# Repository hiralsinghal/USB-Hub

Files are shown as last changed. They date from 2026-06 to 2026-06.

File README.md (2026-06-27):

# USB-Hub

This is a USB hub. It has a USB-C port to connect to the device. It has two USB-A ports and two USB-C ports, which can be used for connecting more devices as it allows you to increase the number of ports available.

## Features

- USB-C port to form the connection between the hub and your device.
- 2 USB-A ports
- 2 USB-C ports

## Schematic

This is the schematic for the USB hub. It has an IC, which makes the hub work. 

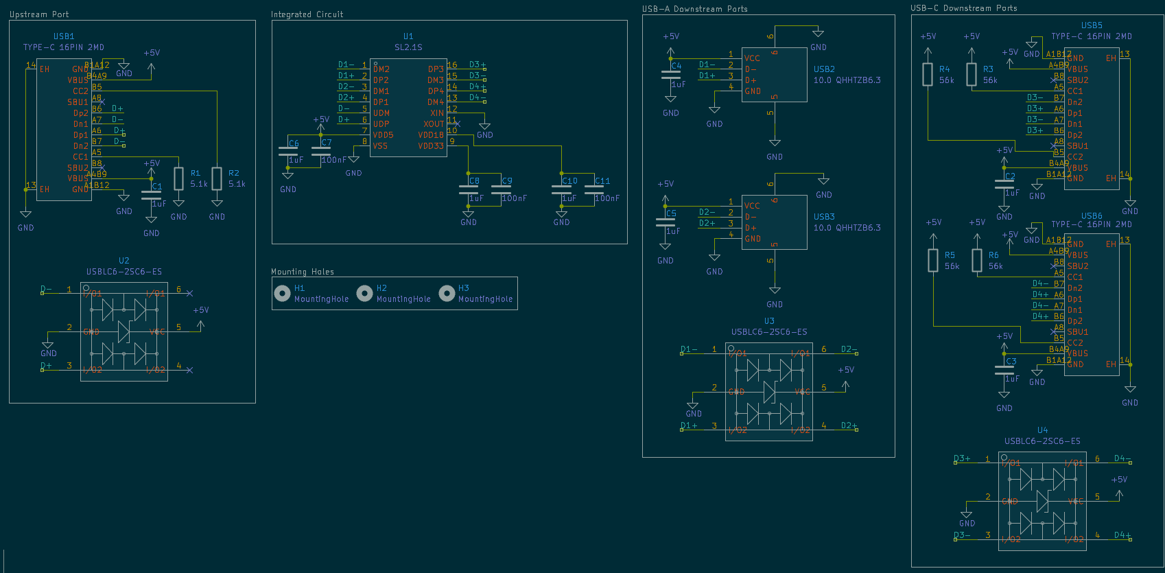
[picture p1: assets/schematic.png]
schematic


### Upstream Port

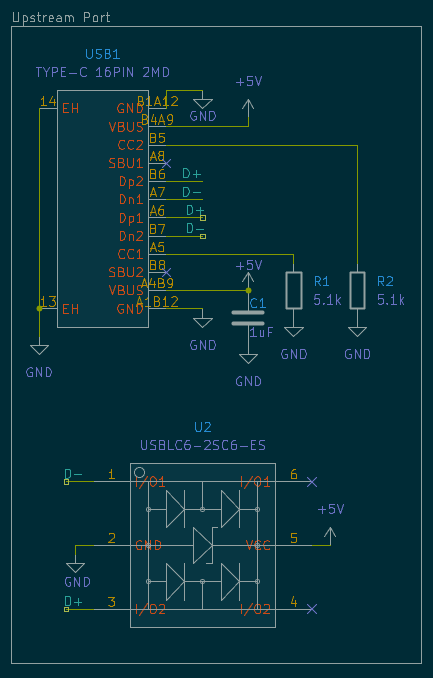
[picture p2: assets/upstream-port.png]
upstream port schematic


### Integrated Circuit

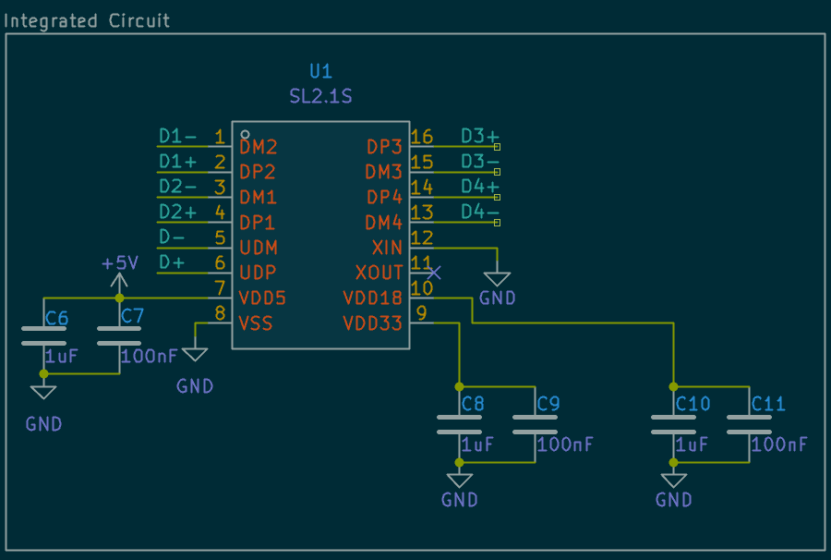
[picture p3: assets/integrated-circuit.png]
integrated circuit schematic


### Downstream Ports

#### USB-A

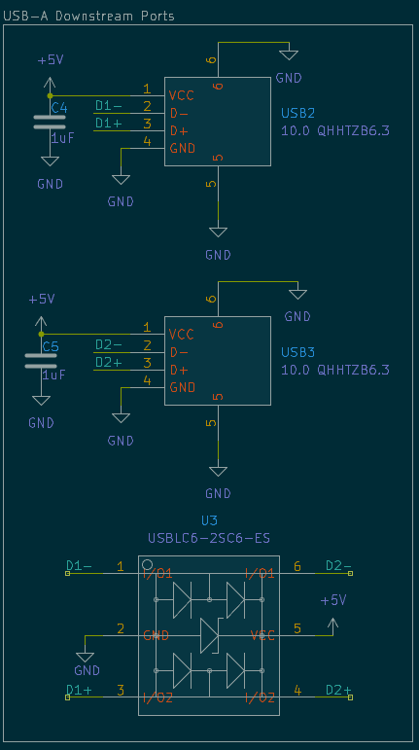
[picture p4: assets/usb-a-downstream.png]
downstream usb-a ports schematic


#### USB-C

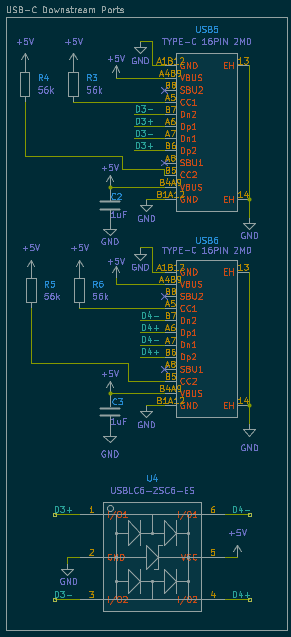
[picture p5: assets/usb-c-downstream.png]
downstream usb-c ports schematic


## PCB

Its just a rounded rectangle shaped PCB and has three mounting holes, so it can be screwed into the case.
I added some quotes as silkscreen art.

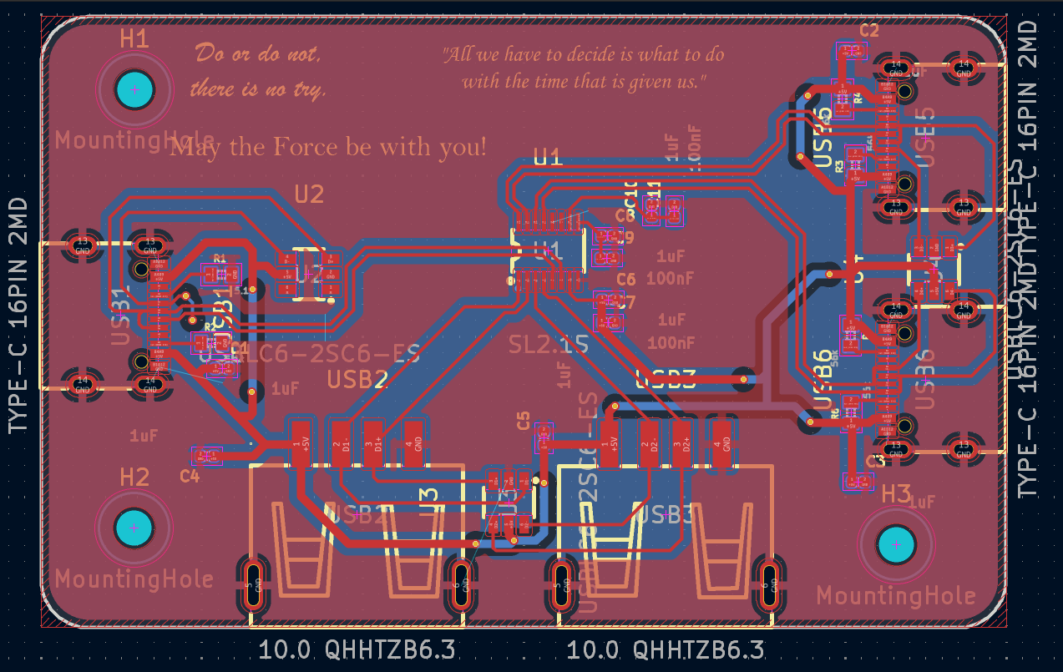
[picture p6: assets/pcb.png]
pcb


**No zones**

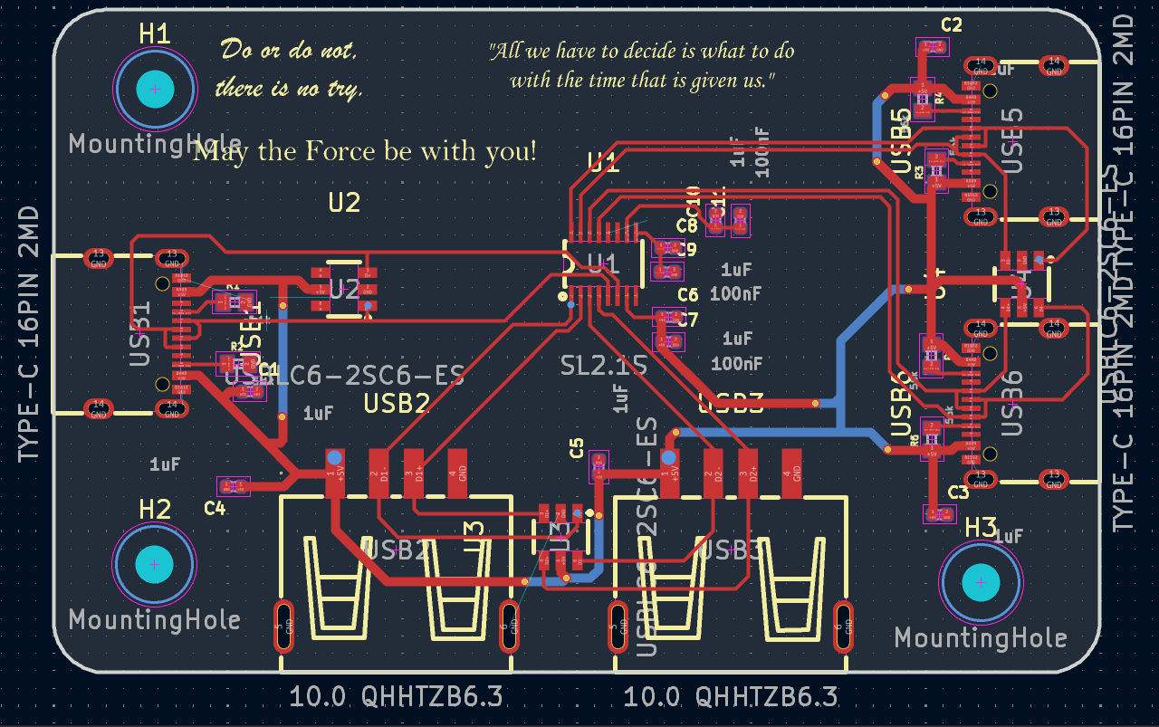
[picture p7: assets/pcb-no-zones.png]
pcb with no filled zones


## Case

I designed this in Fusion, using my PCB as a guide. It has holes for M3 screws so the bottom and top parts hold together. You can find the files in the CAD folder.

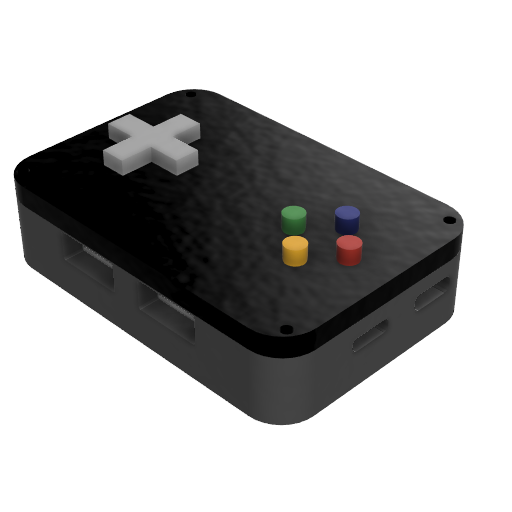
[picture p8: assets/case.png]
case


## BOM

For a more detailed BOM, take a look at [BOM](bom.csv). It has links to the items and notes.

| Item | Description | Quantity | Unit Price ($) | Total Price ($) |
| --- | --- | --- | --- | --- |
| JLCPCB PCB | PCB | 5 | 0.8 | 4 |
| CoreChips SL2.1s | USB 2.0 HUB Controller Integrated Circuit | 5 | 0.2534 | 1.27 |
| SHOU HAN 10.0 QHHTZB6.3 | CONN RCPT USB 2.0 Type-A 4POS SMD R/A | 10 | 0.0636 | 0.64 |
| SHOU HAN TYPE-C 16PIN 2MD(073) | CONN RCPT Type-C 16POS SMD R/A | 20 | 0.0707 | 1.41 |
| ElecSuper USBLC6-2SC6-ES | ESD DIODE 5VWM 15VC SOT-23-6L | 20 | 0.0278 | 0.56 |
| 10k Resistor SMD:R 0402 | Resistor | 6 | 0.0083 | 0.0498 |
| 0.1uf Capacitor SMD:C 0402 | Capacitor | 11 | 0.011 | 0.121 |
| <b>Total</b> | | | | 8.0508 |

## Assembly

- Solder the components to the PCB.
- Print the case.
- Screw the PCB and the bottom case together so its stable.
- Screw the bottom and top case together.
- You have your USB hub!

## Zine

This was designed in Figma. It wasn't easy to make. I had no ideas. I was stuck. Its not my best work.

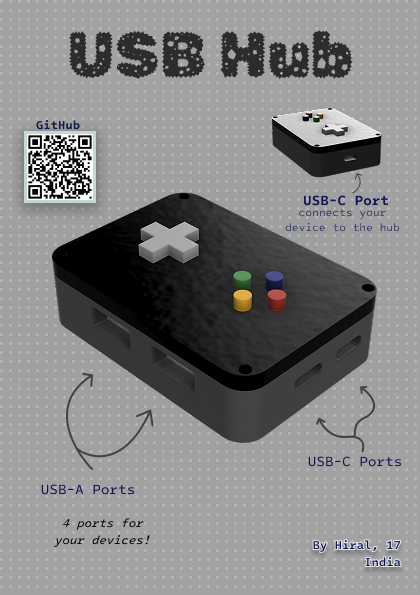
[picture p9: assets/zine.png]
zine


## Why did I make it?

I have been trying to get more into hardware, making guided projets before jumping in to make something my own.
I want to have knowledge on how to do this stuff, so I know how to make my own project.
My routing skills were improved. I made them neatly.

This project was submitted to [Fallout](fallout.hackclub.com).

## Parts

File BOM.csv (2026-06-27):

Item | Description | Quantity | Unit Price ($) | Total Price ($) | URL | Note
PCB | PCB | 5 | 0.8 | 4 |  | JLCPCB is the supplier
CoreChips SL2.1s | USB 2.0 HUB Controller Integrated Circuit | 5 | 0.2534 | 1.27 | https://www.lcsc.com/product-detail/C2684433.html?s_z=n_q_C2684433%2520 | I can't order less than a minimum amount.
SHOU HAN 10.0 QHHTZB6.3 | CONN RCPT USB 2.0 Type-A 4POS SMD R/A | 10 | 0.0636 | 0.64 | https://www.lcsc.com/product-detail/C668591.html?s_z=n_q_C668591&globalKeyword=C668591 | I can't order less than a minimum amount.
SHOU HAN TYPE-C 16PIN 2MD(073) | CONN RCPT Type-C 16POS SMD R/A | 20 | 0.0707 | 1.41 | https://www.lcsc.com/product-detail/C2765186.html?s_z=n_q_C2765186&globalKeyword=C2765186 | I can't order less than a minimum amount.
ElecSuper USBLC6-2SC6-ES | ESD DIODE 5VWM 15VC SOT-23-6L | 20 | 0.0278 | 0.56 | https://www.lcsc.com/product-detail/C5180249.html | I can't order less than a minimum amount.
10k Resistor SMD:R 0402 | Resistor | 6 | 0.0083 | 0.0498 | https://robu.in/product/10k-resistor-smdr-0402-pack-of-50/
0.1uf Capacitor SMD:C 0402 | Capacitor | 11 | 0.011 | 0.121 | https://robu.in/product/1uf-capacitor-smdc-0402-pack-of-50/
Total |  |  |  | 8.0508

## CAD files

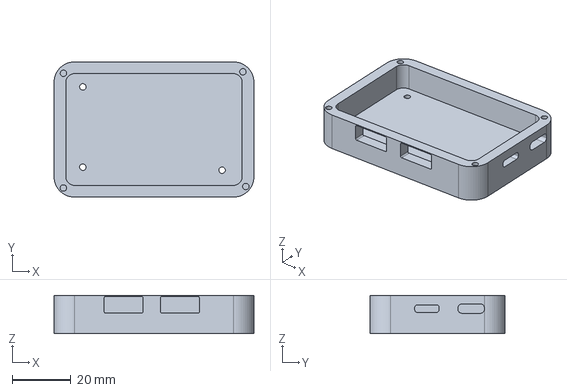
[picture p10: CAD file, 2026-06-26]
CAD/bottom-case.step
68.0 x 46.0 x 13.0 mm

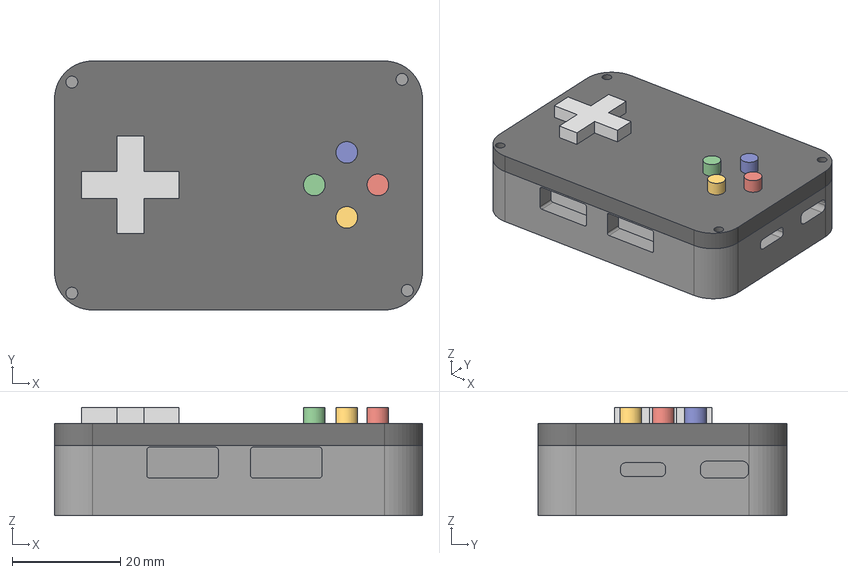
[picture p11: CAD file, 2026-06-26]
CAD/case.step
68.0 x 46.0 x 20.0 mm

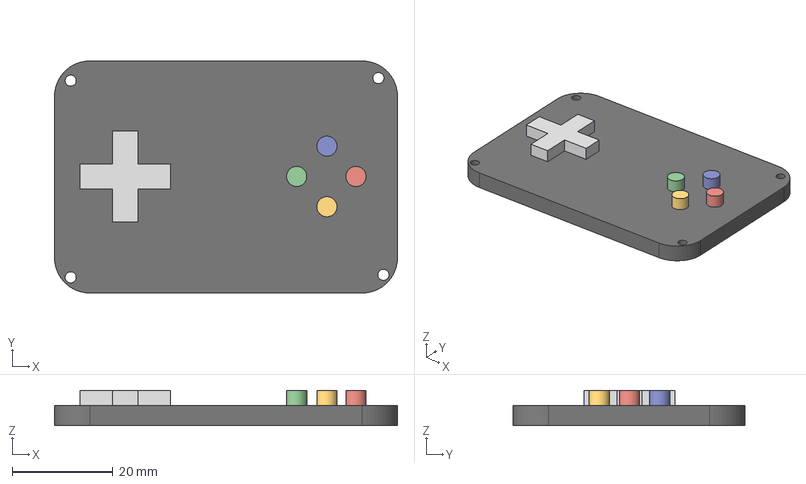
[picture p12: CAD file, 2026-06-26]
Production/top-case.step
68.0 x 46.0 x 7.00 mm

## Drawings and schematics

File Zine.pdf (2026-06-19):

# USB Hub

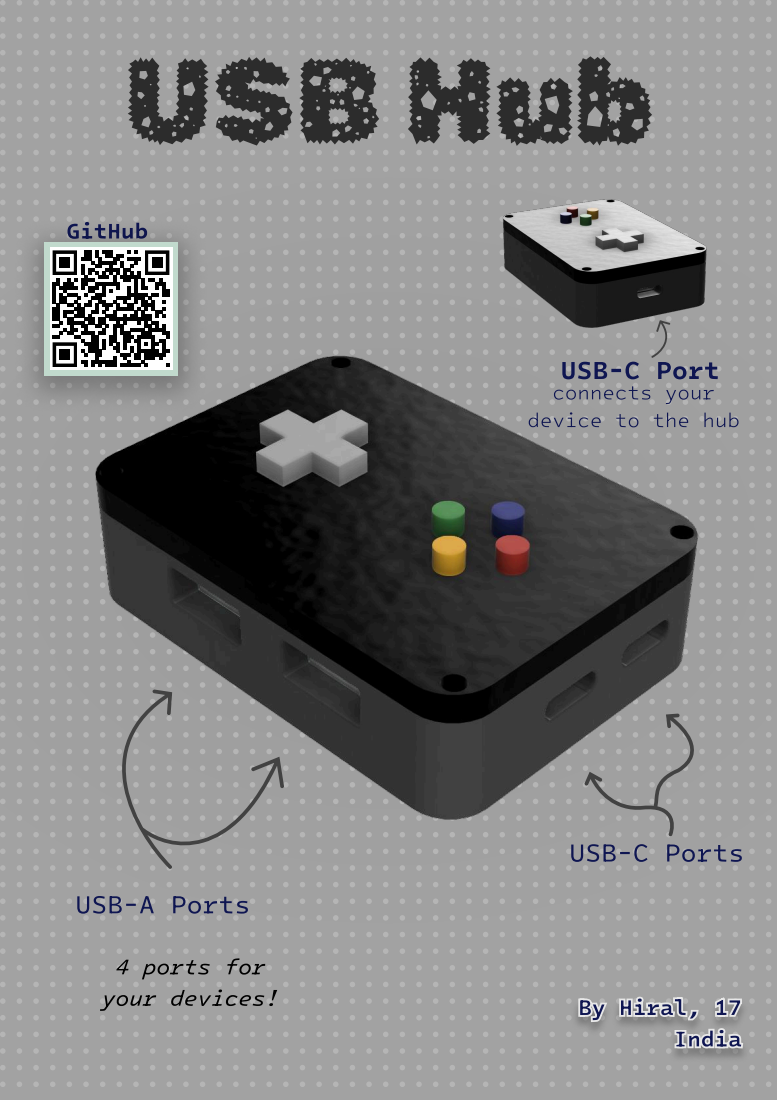
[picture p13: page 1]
GitHub; USB-A Ports; 4 ports for; your devices!; By Hiral, 17; India; USB-C Ports

USB-C Port
connects your
device to the hub

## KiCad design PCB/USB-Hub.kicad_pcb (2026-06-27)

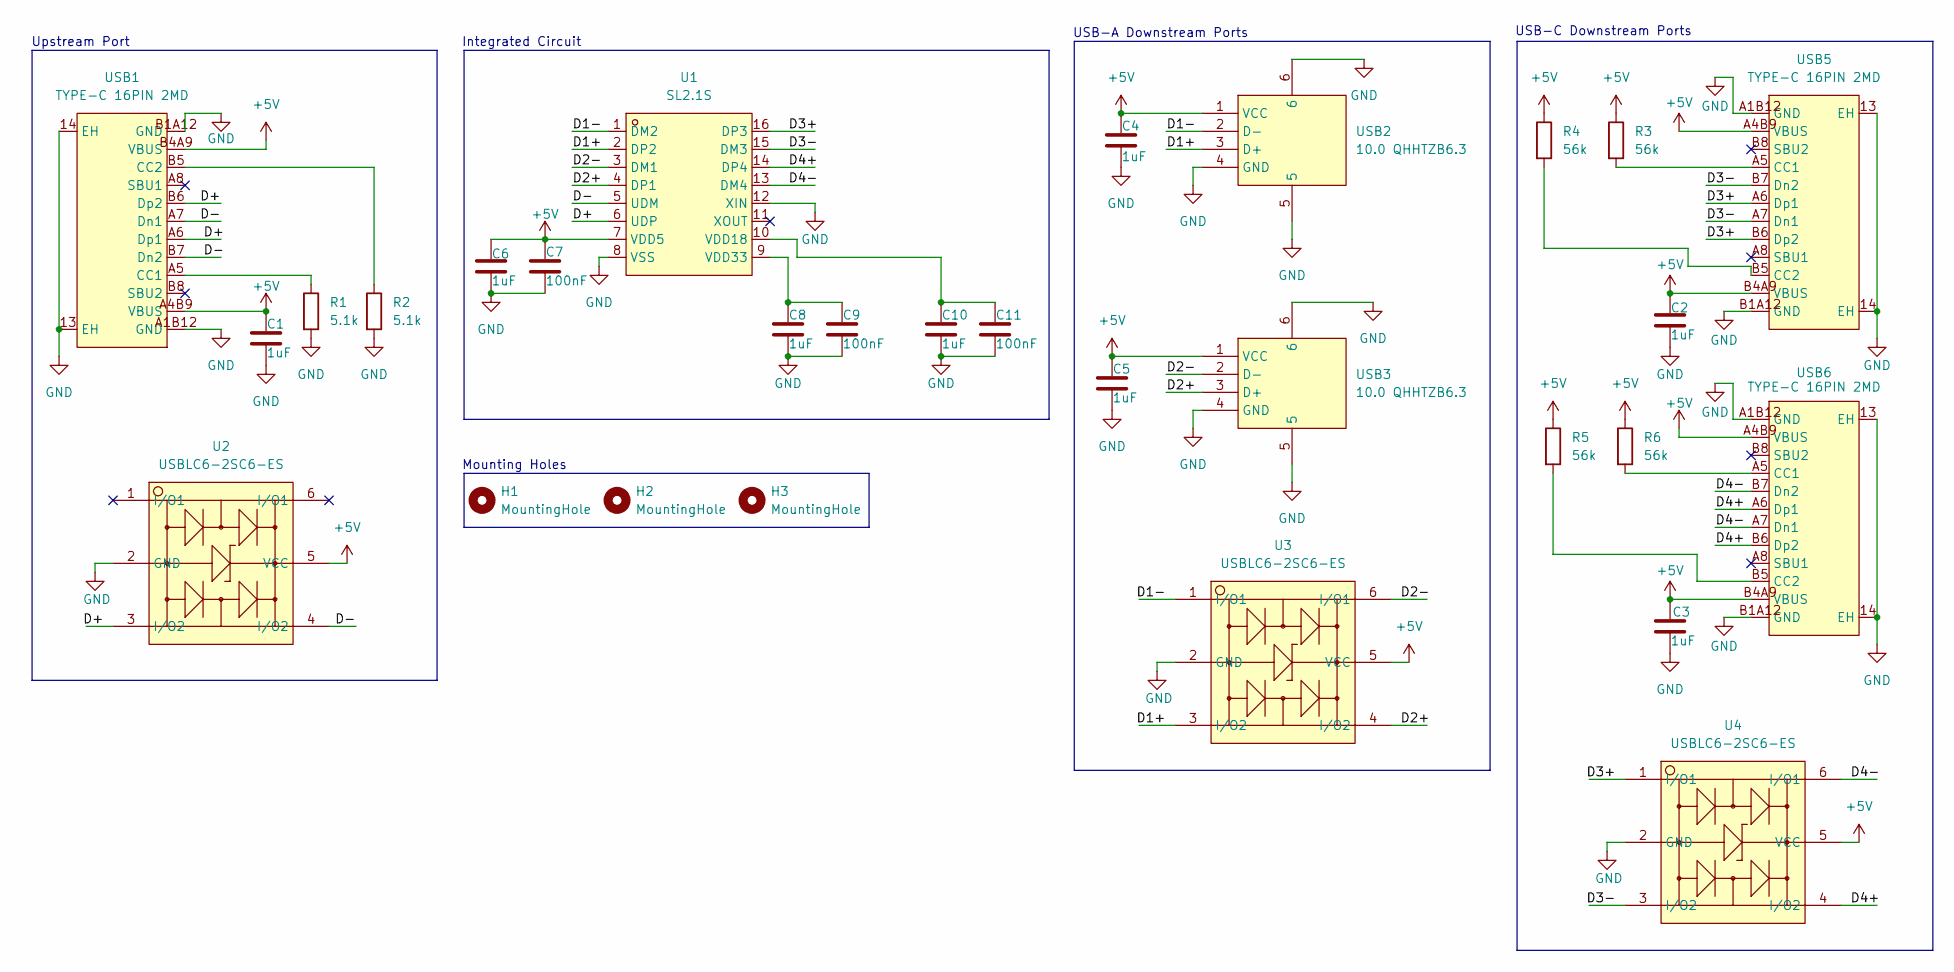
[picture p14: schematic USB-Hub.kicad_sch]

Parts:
C1, C2, C3, C4, C5, C6, C8, C10: 1uF; CAPC1005X55N
C7, C9, C11: 100nF; CAPC1005X55N
H1, H2, H3: MountingHole; MountingHole_2.2mm_M2
R1, R2: 5.1k; CAPC1005X60
R3, R4, R5, R6: 56k; CAPC1005X60
U1: SL2.1S; SSOP-16_L4.6-W2.6-P0.53-LS4.0-BL; MPN SL2.1s; LCSC Part C2684433
U2, U3, U4: USBLC6-2SC6-ES; SOT-23-6_L2.9-W1.6-P0.95-LS2.8-BR; MPN USBLC6-2SC6-ES; LCSC Part C5180249
USB1, USB5, USB6: TYPE-C 16PIN 2MD; USB-C-SMD_TYPE-C-16PIN-2MD-073; MPN TYPE-C 16PIN 2MD(073); LCSC Part C2765186
USB2, USB3: 10.0 QHHTZB6.3; USB-A-TH_10.0QHHTZB6.3; MPN 10.0 QHHTZB6.3; LCSC Part C668591

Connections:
+5V: C1.1, C2.1, C3.1, C4.1, C5.1, C6.1, C7.1, R3.1, R4.1, R5.1, R6.1, U1.7 (VDD5), U2.5 (VCC), U3.5 (VCC), U4.5 (VCC), USB1.A4B9 (VBUS), USB1.B4A9 (VBUS), USB2.1 (VCC), USB3.1 (VCC), USB5.A4B9 (VBUS), USB5.B4A9 (VBUS), USB6.A4B9 (VBUS), USB6.B4A9 (VBUS)
/D1+: U1.2 (DP2), U3.3 (I/O2), USB2.3 (D+)
/D1-: U1.1 (DM2), U3.1 (I/O1), USB2.2 (D-)
/D2+: U1.4 (DP1), U3.4 (I/O2), USB3.3 (D+)
/D2-: U1.3 (DM1), U3.6 (I/O1), USB3.2 (D-)
/D3+: U1.16 (DP3), U4.1 (I/O1), USB5.A6 (Dp1), USB5.B6 (Dp2)
/D3-: U1.15 (DM3), U4.3 (I/O2), USB5.A7 (Dn1), USB5.B7 (Dn2)
/D4+: U1.14 (DP4), U4.4 (I/O2), USB6.A6 (Dp1), USB6.B6 (Dp2)
/D4-: U1.13 (DM4), U4.6 (I/O1), USB6.A7 (Dn1), USB6.B7 (Dn2)
/D+: U1.6 (UDP), U2.3 (I/O2), USB1.A6 (Dp1), USB1.B6 (Dp2)
/D-: U1.5 (UDM), U2.4 (I/O2), USB1.A7 (Dn1), USB1.B7 (Dn2)
GND: C1.2, C2.2, C3.2, C4.2, C5.2, C6.2, C7.2, C8.2, C9.2, C10.2, C11.2, R1.2, R2.2, U1.8 (VSS), U1.12 (XIN), U2.2 (GND), U3.2 (GND), U4.2 (GND), USB1.13 (EH), USB1.14 (EH), USB1.A1B12 (GND), USB1.B1A12 (GND), USB2.4 (GND), USB2.5, USB2.6, USB3.4 (GND), USB3.5, USB3.6, USB5.13 (EH), USB5.14 (EH), USB5.A1B12 (GND), USB5.B1A12 (GND), USB6.13 (EH), USB6.14 (EH), USB6.A1B12 (GND), USB6.B1A12 (GND)
unnamed: C10.1, C11.1, U1.10 (VDD18)
unnamed: C8.1, C9.1, U1.9 (VDD33)
unnamed: R1.1, USB1.A5 (CC1)
unnamed: R2.1, USB1.B5 (CC2)
unnamed: R3.2, USB5.A5 (CC1)
unnamed: R4.2, USB5.B5 (CC2)
unnamed: R6.2, USB6.A5 (CC1)
unnamed: R5.2, USB6.B5 (CC2)

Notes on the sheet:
USB-C Downstream Ports
Upstream Port
Mounting Holes
USB-A Downstream Ports
Integrated Circuit

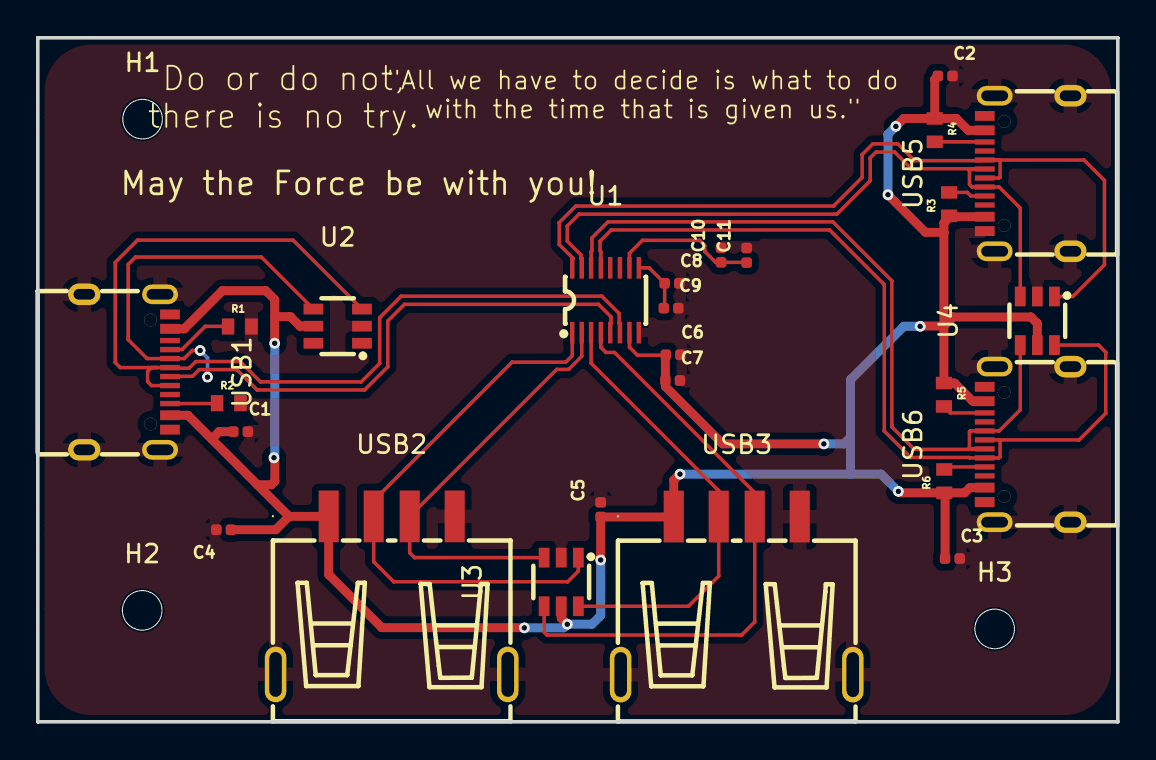
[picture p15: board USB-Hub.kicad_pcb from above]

Board: 2 copper layers, 60.0 x 38.0 mm, 29 parts (0 on the bottom side), 20 nets.

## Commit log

2026-06-17 readme, pcb folder, bom
    [BOM.csv, USB-Hub.kicad_pcb, USB-Hub.kicad_sch]
2026-06-18 bom and readme
    [BOM.csv]
2026-06-18 bom update
    [BOM.csv]
2026-06-18 cad stuff
    [bottom-case.step, top-case.step]
2026-06-26 update bom,readme
    [BOM.csv]
2026-06-26 update pcb
2026-06-26 remove old files
    [USB-Hub.kicad_pcb, USB-Hub.kicad_sch]
2026-06-26 update gerbers
2026-06-26 update pcb files
    [USB-Hub.kicad_pcb, USB-Hub.kicad_sch]
2026-06-26 remove files
    [bottom-case.step, top-case.step]
2026-06-26 cad and bom update
    [BOM.csv, bottom-case.step, top-case.step]
2026-06-26 remove the filess aahh
    [bottom-case.step]
2026-06-26 add the newest cad files finally
    [bottom-case.step, case.step]
